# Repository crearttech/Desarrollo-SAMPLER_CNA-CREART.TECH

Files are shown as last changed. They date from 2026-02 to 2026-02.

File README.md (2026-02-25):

# DESARROLLO DE SAMPLER

**Looper / Sampler de audio en tiempo real construido sobre Daisy Seed.**

SAMPLER es un dispositivo de audio portátil que permite grabar, reproducir, sobreponer capas (overdub) y manipular loops en tiempo real con efectos y control visual mediante pantalla TFT.

Proyecto desarrollado por **Crearttech** y entregado al **CNA Centro Nacional de las Artes Delia Zapata Olivella** en Bogotá, Colombia.

---

## Características

- **Grabación y Reproducción** — Loop de hasta 10 segundos a 48kHz
- **Overdub** — Sobregrabar capas sobre el loop existente
- **Efectos en tiempo real** — Delay, Reverb, Pitch Shift, Filtros HP/LP
- **Reproducción reversa** — Inversión de la dirección de playback
- **Control de región** — Start/End point y movimiento del loop
- **Undo/Redo** — 3 niveles de historial
- **Pantalla TFT** — Visualización de waveform en tiempo real con interfaz de knobs circulares
- **Crossfade automático** — Transiciones suaves al cerrar el loop
- **Detección de jack** — Cambio automático entre entrada de línea y micrófono

## Hardware

| Componente | Descripción |
|---|---|
| Microcontrolador | Electro-Smith Daisy Seed (ARM Cortex-M7) |
| Pantalla | TFT ST7735 128×160 |
| Entrada de audio | ADC integrado del Daisy Seed |
| Salida de audio | DAC integrado del Daisy Seed |
| Controles | 4 Encoders rotativos con botón, 6 botones, LED RGB |

## Estructura del Código

```
SAMPLER_CNA/
├── SAMPLER_CNA.ino          # Programa principal (UI, controles, audio callback)
├── sampler_engine.h         # Motor de audio (grabación, playback, overdub, undo/redo)
├── sampler_effects.h        # Módulo de efectos (reverse, pitch shift, filtros)
├── sampler_dsp_utils.h      # Utilidades DSP optimizadas con CMSIS-DSP
├── sampler_state_machine.h  # Máquina de estados del looper
├── sampler_sync.h           # Sincronización de tempo y clock
└── sampler_hardware.h       # Mapeo de pines del Daisy Seed
```

## Instalación

1. Instalar [Arduino IDE](https://www.arduino.cc/en/software)
2. Instalar el board package **Electrosmith Daisy** desde el Board Manager
3. Instalar las bibliotecas:
   - `DaisyDuino`
   - `Adafruit GFX Library`
   - `Adafruit ST7735`
4. Abrir `SAMPLER_CNA/SAMPLER_CNA.ino`
5. Seleccionar board **Daisy Seed** y el puerto correspondiente
6. Compilar y subir

## Desarrolladores

**Crearttech**
- Andrés Melo
- Kelly Melo
- Rodrigo Aguilar

**En colaboración con DELIA**
- Javier Beltrán
- Santiago Gasca

**Crearttech** — Bogotá, Colombia, 2024

Proyecto entregado al **CNA Centro Nacional de las Artes Delia Zapata Olivella**, Bogotá, Colombia.

---

## Bibliografía y Referencias

### Hardware y Librerías Base
- **Electro-Smith**. (2020). *Daisy Seed Datasheet & Wiki*. [Daisy Seed Documentation](https://www.electro-smith.com/daisy/daisy).
- **DaisyDuino**. *Librería de soporte para el ecosistema Daisy en Arduino*. [GitHub Repository](https://github.com/electro-smith/DaisyDuino).
- **Adafruit Industries**. *Adafruit GFX Graphics Library*. [Documentation](https://learn.adafruit.com/adafruit-gfx-graphics-library).

### Procesamiento Digital de Señales (DSP)
- **Smith, S. W.** (1997). *The Scientist and Engineer's Guide to Digital Signal Processing*. California Technical Publishing.
- **Pirkle, W. C.** (2012). *Designing Audio Effect Plug-ins in C++*. Focal Press.
- **Zölzer, U.** (2011). *DAFX: Digital Audio Effects*. Wiley.

### Optimización y Algoritmos
- **ARM**. *CMSIS DSP Software Library Documentation*. [ARM Developer](https://arm-software.github.io/CMSIS_5/DSP/html/index.html).
- **D’Angelo, S., & Välimäki, V.** (2013). *Generalized Moog Ladder Filter*.

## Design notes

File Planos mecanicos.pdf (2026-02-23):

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

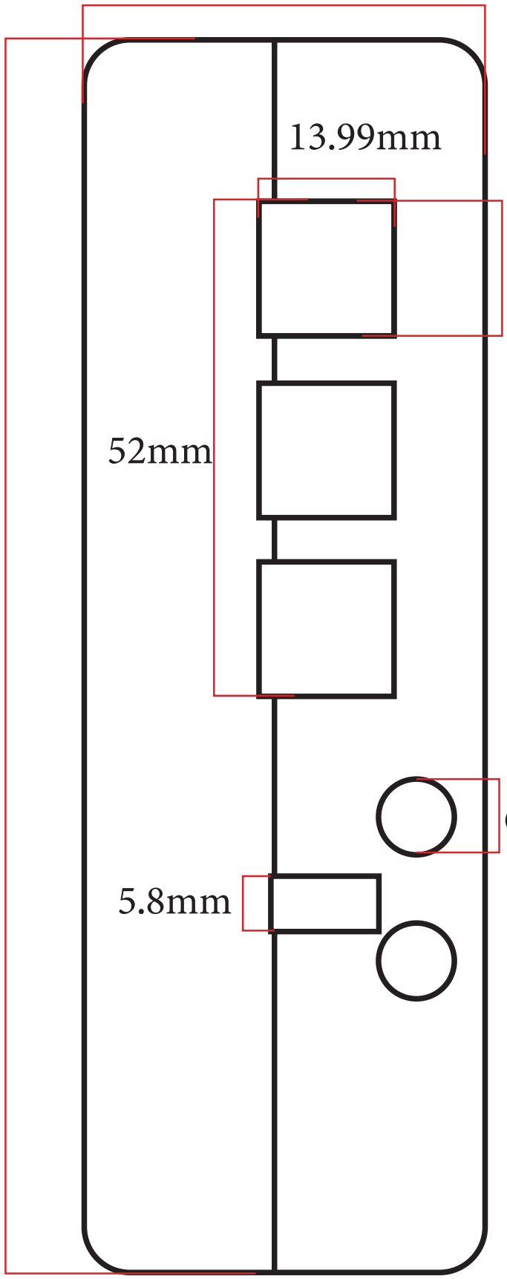
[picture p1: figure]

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

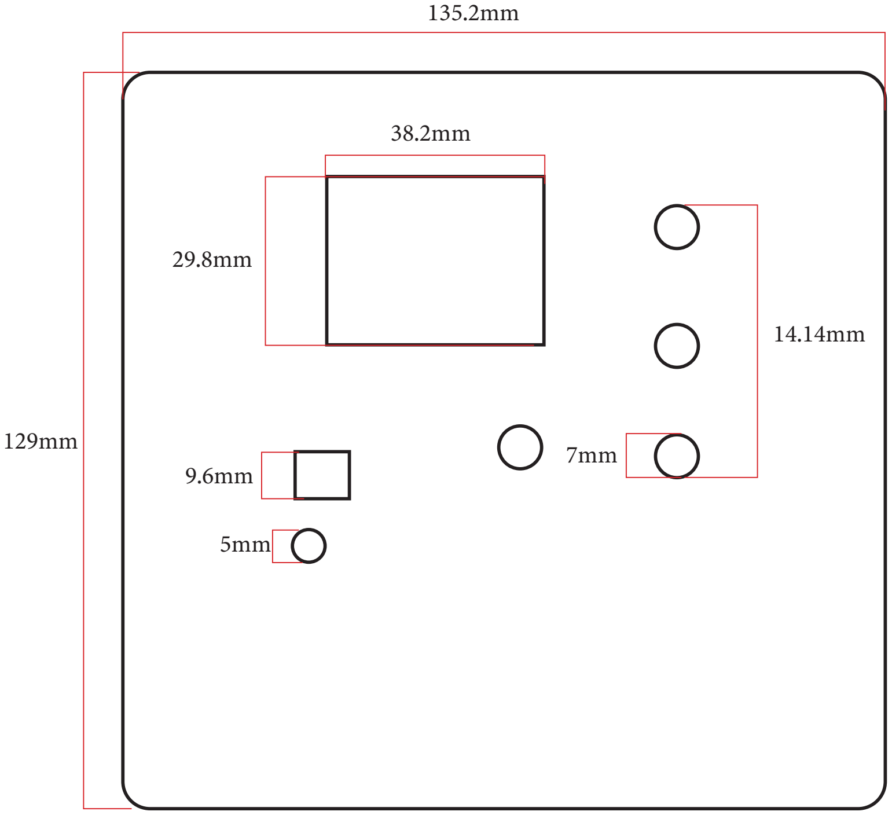
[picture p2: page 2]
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

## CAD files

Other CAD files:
PLANOS_MECANICOS_CASE.stl

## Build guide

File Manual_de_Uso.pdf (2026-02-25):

MANUAL DE USO

CODESARROLLO DE INSTRUMENTO ELECTRÓNICO MUSICAL

SAMPLER CNA + CREART.TECH

CENTRO NACIONAL DE LAS ARTES DELIA ZAPATA OLIVELLA

Bogotá D.C , Colombia

MANUAL DE USO

CODESARROLLO DE INSTRUMENTO ELECTRÓNICO MUSICAL

SAMPLER CNA + CREART.TECH

Presentado por :

CREART.TECH (SOUNDIFY STUDIO)

a

CENTRO NACIONAL DE LAS ARTES DELIA ZAPATA OLIVELLA

Bogotá D.C , Colombia

### 22 DE DICIEMBRE DE 2025

ÍNDICE :

1. Introducción
2. Conociendo el sampler
3. Encendido y flujo básico
4. Botones y Encoders
5. Guia de navegación
6. Exploración creativa
7. Integración
8. Resolución de problemas
9. Especificaciones técnicas
10. Glosario de términos

### 01. Introducción

Sampler CNA + Creart.Tech es una grabadora-sampler creativa basada en Daisy Seed, diseñada para capturar y manipular audio en tiempo real. Permite registrar sonidos, momentos e ideas, y procesarlos mediante coloración, modulación y edición sonora.

Es un instrumento versátil y preciso, listo para ser explorado, reinterpretado y llevado a nuevos territorios creativos.

Principios de diseño:

### 02. Conociendo el sampler

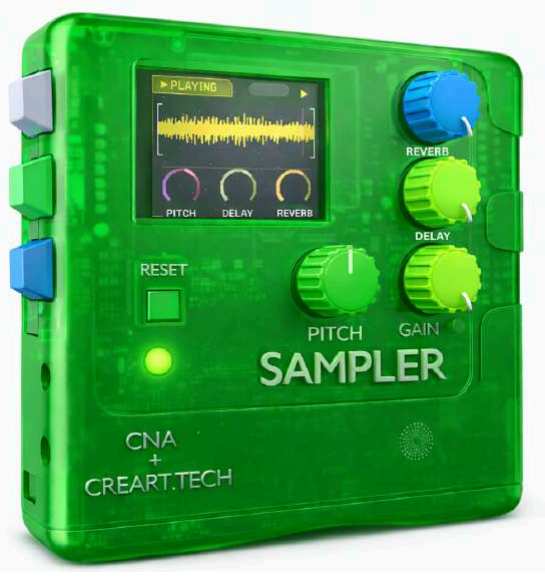
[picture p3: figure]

- Controles y conectores:
- Micrófono integrado (I2S)
- Entrada de línea 3.5 mm
- Encoders laterales y central
- Pantalla TFT
- LED de estado
- 3 teclas arcade

### 03. Encendido y flujo básico

Encendido:
Conecte un cable micro usb al microcontrolador Daisy seed. Espere a que la barra de carga se complete; cuando la interfaz esté activa, el dispositivo estará listo para su uso.

- Primer ejercicio rápido (“Quick Start”):

### 3 pasos para grabar y tocar un loop (ejercicio inmediato)

1. Mantener presionado el botón REC / OVERDUB, durante el tiempo que se desee que dure el sample.
2. Encoder GAIN, girando en sentido horario y antihorario.
3. Se presiona Encoder 1, se gira en sentido horario y antihorario para establecer punto de inicio; se presiona nuevamente Encoder 1 y se gira en sentido horario y antihorario para establecer punto de fin.
- Flujo funcional (Captura → Procesamiento → Reproducción → Efectos)

### 04. Botones y Encoders

Cada botón y encoder explicado con visual + acciones:
Grabación - Edición - Efectos

TECLA / BOTÓN 1:

REC / OVERDUB

Para una captura inicial, se debe mantener pulsado el botón durante todo el tiempo de grabación y soltar en el instante en el que se quiere detener la grabación. Una vez se deja de presionar el botón, el sampler, entra en modo loop, reproduciendo esta primera toma. Para hacer un OVERDUB, se debe presionar nuevamente el botón de manera sostenida durante toda la captura que se desea hacer y se debe soltar una vez haya terminado la captura.

TECLA / BOTÓN 2:

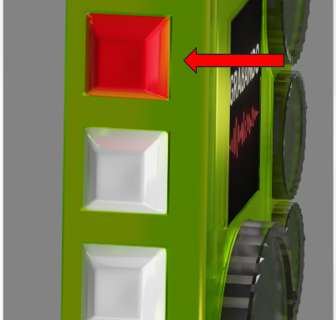
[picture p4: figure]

PLAY / PAUSE

Se presiona el botón una vez para detener la reproducción de audio y se debe presionar nuevamente una única vez para reanudar la reproducción del audio. Pulsando dos veces el mismo botón, sampler, entra en modo stop y se borrará todo el contenido grabado.

TECLA / BOTÓN 3:

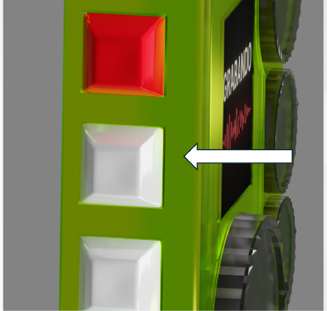
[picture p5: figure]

PLAYBACK - FORWARD / BACKWARD

Empieza a reproducir el audio por defecto hacia adelante. Se debe presionar el botón para backward que permite reproducir el loop en reversa, invirtiendo la dirección temporal del audio grabado.

TECLA / BOTÓN 4:

CUE / RESET

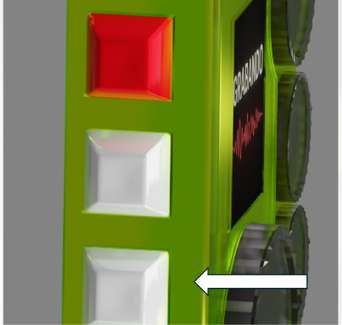
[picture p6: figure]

Se presiona una vez para volver al punto de inicio que se tenga marcado (cue) ya sea por defecto o por el punto de inicio de loop. Este botón permite reiniciar los efectos sin afectar el audio en curso. Pulsado una vez, se resetea el último cambio aplicado al audio y con dos pulsaciones resetea todos los cambios incluyendo el punto de inicio y punto de final del loop.

Encoder 1 (Reverb)

Controla los parámetros del efecto de Reverb. Tiene tres parámetros que se pueden alternar con una pulsación para cambiar entre ellos y son: MIX, SIZE y DECAY. Al cambiar de modo, el contador del encoder se actualiza al valor guardado que se puede establecer con el giro del encoder, modificando el valor del parámetro actualmente seleccionado (de 0% a 100%), girando el encoder en sentido horario y antihorario para mover el cursor de izquierda a derecha o de derecha a izquierda respectivamente.

Encoder 2 (Delay)

Controla los parámetros del efecto de Delay. Tiene tres parámetros que se pueden alternar con una pulsación para cambiar entre ellos y son: MIX, TIME y FEEDBACK. Al cambiar de modo, el contador del encoder se actualiza al valor guardado que se puede establecer con el giro del encoder, modificando el valor del parámetro actualmente seleccionado (de 0% a 100%), girando el encoder en sentido horario y antihorario para mover el cursor de izquierda a derecha o de derecha a izquierda respectivamente.

Encoder 3 (GAIN, START/END POINT & MOVE)

Permite ajustar cuatro parámetros principales: Gain, Start Point, End Point y Move. Cada vez que se presiona el encoder, se avanza al siguiente modo de edición en el orden indicado.

### 1. Modo Gain (por defecto)

- El encoder ajusta el volumen de la muestra.
- Girar en sentido horario aumenta el nivel; girar en sentido antihorario disminuye el nivel.
- Aunque el encoder tiene rotación continua, el volumen está limitado entre 0 % y 100 %.
- Para confirmar el nivel de volumen y continuar al siguiente parámetro, presionar el encoder.

### 2. Modo Start Point

- Tras la pulsación, el encoder pasa a controlar el punto de inicio del loop.
- Girar en sentido horario mueve el cursor de inicio hacia la derecha; en sentido antihorario, hacia la izquierda.
- Una vez establecido el punto de inicio, presionar el encoder para fijarlo y pasar al siguiente parámetro.

### 3. Modo End Point

- El encoder permite definir el punto de final del loop.
- Girar en sentido horario mueve el cursor hacia la derecha; en sentido antihorario, hacia la izquierda.
- Al confirmar el punto de final con una pulsación, se avanza al último modo.

### 4. Modo Move

- En este modo, el encoder desplaza el loop completo, moviendo simultáneamente el Start Point y el End Point.
- Girar en sentido horario desplaza el loop hacia la derecha; girar en sentido antihorario lo desplaza hacia la izquierda.
- Una nueva pulsación regresa el encoder nuevamente al modo Gain.

Encoder 4 Central (Pitch & Filtros)

PITCH
Controla el pitch girando el encoder en sentido horario y antihorario para mover el cursor de inicio de izquierda a derecha o de derecha a izquierda respectivamente, lo que cambia el valor de pitch, que se traduce directamente en la transposición de semitonos. El rango está limitado de -128 semitonos a +128 semitonos. Con una pulsación del botón de CUE/RESET, se resetea el pitch a 0 semitonos, lo que permite regresar a la tonalidad original. Este rango en semitonos abarca tanto 10 octavas + 8 semitonos de forma ascendente así como 10 octavas + 8 semitonos de forma descendente.

FILTROS
Este modo permite quitar contenido frecuencial de la muestra, girando el encoder en sentido horario y antihorario para mover el cursor de izquierda a derecha o de derecha a izquierda respectivamente, permitiendo elegir la frecuencia de corte comprendidas entre 20Hz y 20kHz permitiendo filtrar el contenido a partir de dicha frecuencia.

High Pass

Pulsando una vez el encoder, luego de haber establecido un valor de pitch, se podrá cambiar la frecuencia de corte del filtro high pass, permitiendo pasar todo el contenido frecuencial a partir de la frecuencia de corte en adelante (las frecuencias altas).

Con una pulsación del botón de CUE/RESET, se resetea el filtro aplicado.

Low Pass
Luego con otra pulsación, luego de haber establecido una frecuencia de corte para el filtro high pass, se podrá cambiar la frecuencia de corte del filtro low pass, permitiendo pasar todo el contenido frecuencial a partir de la frecuencia de corte hacia atrás (las frecuencias bajas).

Con una pulsación del botón de CUE/RESET, se resetea el filtro aplicado.

### 0.5 Guia de navegación

Control físico | Acción del usuario | Función asignada | Criterio de diseño / Uso musical

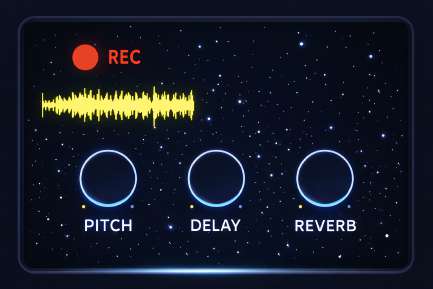
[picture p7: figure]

| Botón 1 REC | Mantener pulsado | Inicia la grabación del loop | Permite control preciso de la duración del loop
| | Soltar | Finaliza grabación e inicia reproducción | Flujo natural grabar → reproducir
| | Pulsación posterior | Activa modo Overdub | Superposición de capas sonoras sin interrumpir ejecución

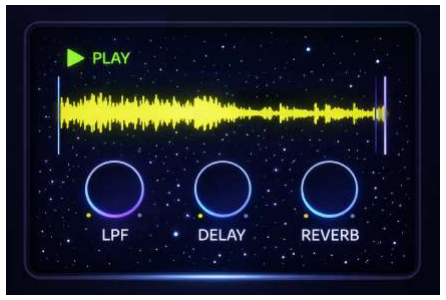
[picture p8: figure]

| Botón 2 | Pulsación simple | Play / Pause del loop | Detener y reanudar sin reiniciar

Transporte

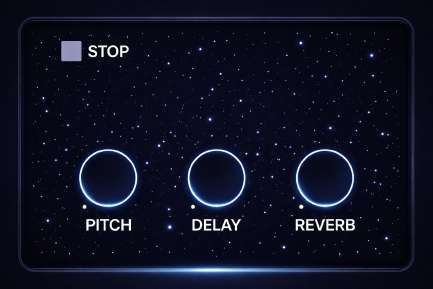
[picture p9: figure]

| Doble pulsación | Stop y borrado de audio | Reinicio rápido del buffer de memoria

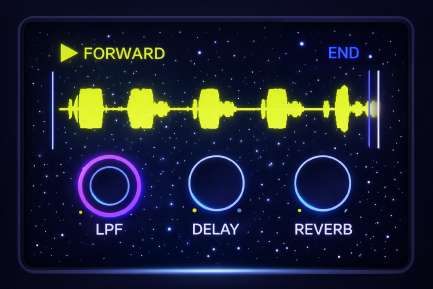
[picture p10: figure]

Botón 3 Dirección | Pulsación | Forward (por defecto) | Reproducción temporal estándar
| Pulsación alterna | Backward | Reproducción en reversa para exploración expresiva

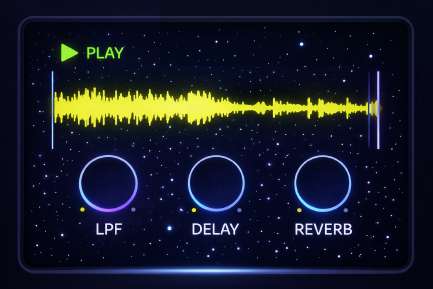
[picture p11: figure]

Botón 4 Reset | Pulsación simple | Reset de efectos | Limpieza sonora sin afectar el audio
| Doble pulsación | Reset de Start Point y End Point | Reconfiguración estructural del loop

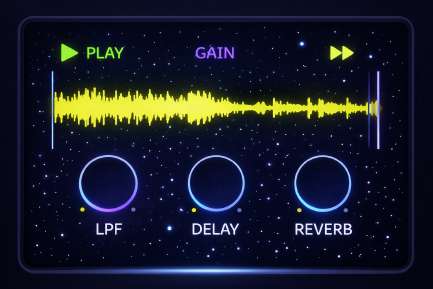
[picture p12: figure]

Encoder 1 Loop | Pulsación | Cambio de modo | Navegación entre parámetros del loop
| Giro | Gain | Control de amplitud del audio

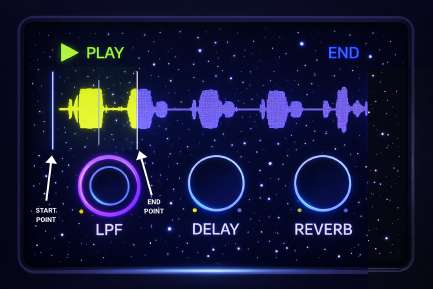
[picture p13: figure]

| Giro | Start Point | Ajuste del punto de inicio del loop
| Giro | End Point | Ajuste del punto final del loop
| Giro | Move | Desplazamiento temporal del loop

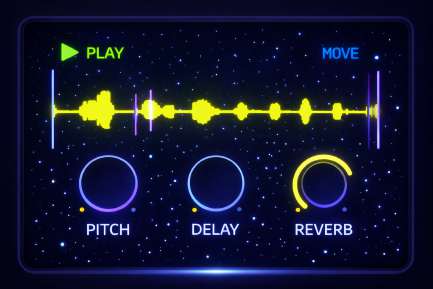
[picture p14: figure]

Encoder 2 Reverb | Pulsación | Cambio de modo (MIX / SIZE / DECAY) | Navegación simple sin menús
| Giro | Ajuste de parámetro (0–100) | Control progresivo y continuo

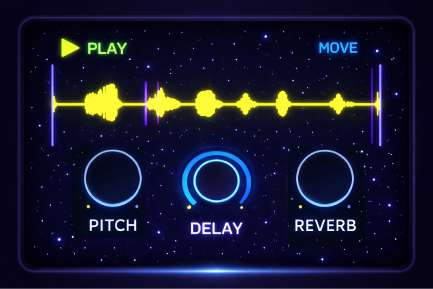
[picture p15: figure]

Encoder 3 Delay | Pulsación | Cambio de modo (TIME / FEEDBACK / MIX) | Control estructurado del efecto
| Giro | Ajuste de parámetro (0–100) | Manipulación expresiva del tiempo

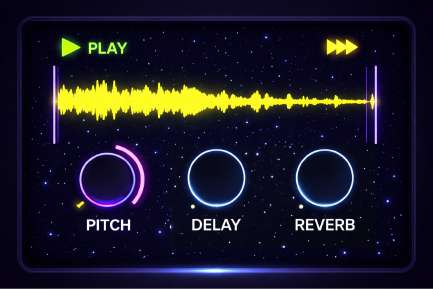
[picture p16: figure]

Encoder 4 Pitch | Giro | ±7 semitonos | Modifica afinación y velocidad del loop
| | Agudo | Reproducción más rápida
| | Grave | Reproducción más lenta

Encoder 4 Filtros | Giro | High-Pass | Eliminación de frecuencias bajas
| Giro | Low-Pass | Eliminación de frecuencias altas

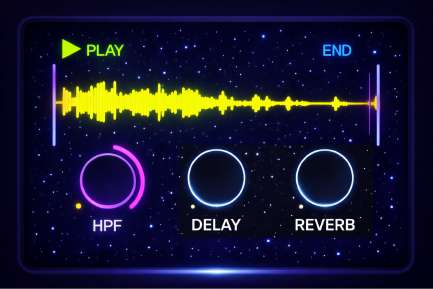
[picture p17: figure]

### 06. Exploración creativa

Ejemplos de uso artístico:

“Grabe un sonido cotidiano y conviértalo en ritmo.”

Grabe un ritmo sencillo, puede golpear una mesa con las manos, haga chopping para conservar sólo el instante en el que se percibe el fragmento del golpe cortando así todo lo demás que se haya podido colar en la grabación, aplique filtros high pass y low pass, cortando el contenido frecuencial innecesario sin cortar demasiado evitando filtrar el ataque en alta frecuencia y el cuerpo en baja presencia, puede bajar la tonalidad un par de semitonos para un sonido más grave, aplicar reverb, con un size mediano, un decay corto y un mix entre el 20% y 40% (puede explorar distintos valores según el gusto).

RESULTADO: obtendrá un sonido más espaciado y por tanto un bombo al son de tu ritmo.

“Transforme un susurro en un pad atmosférico”

Capture un susurro o respiración suave, baje el pitch para alargar la sensación y dar más cuerpo. use low-pass para suavizar y high-pass para limpiar graves innecesarios, puede jugar con el punto de corte para moldear el timbre. Aplique un delay con feedback bajo y tiempo largo para simular movimiento y repetición, agregue una reverb extensa (decay alto, mix 60–80%) para generar la atmósfera envolvente.

RESULTADO: un pad etéreo que se construye con capas de pitch + delay + reverb, sin necesidad de time-stretch ni moduladores.

“Construya percusión con objetos metálicos”
Grabe el sonido de llaves, monedas o utensilios metálicos, corte los fragmentos más brillantes y cortos para usarlos como hits, baje algunos samples para simular percusión grave (tipo toms) y suba otros para hi-hats. Use low-pass para dar cuerpo a los graves y high-pass para resaltar los agudos metálico, aplique delay rítmico sincronizado al tempo para crear patrones repetitivos y agregue reverb corta y controlada para dar cohesión sin perder ataque.

RESULTADO: un kit alternativo de percusión metálica, con carácter industrial y experimental.

### 07. Integración

- Conexión a otros equipos: pedales, sintetizadores, interfaces y Daws.

TIPO DE CONEXIONES EXTERNAS PERMITIDAS PARA sampler

Solo conectores TRS de 3.5mm o de 6.35mm con su respectivo adaptador a 3.5mm, o cualquier otro tipo de adaptador que permita físicamente hacer la conexión y que se respete el nivel y la impedancia de un conector TRS.
❖ Una señal de línea por conector TRS suele tener un nivel típico entre –10 dBV (≈ 0,316V RMS) e idealmente +4 dBu (≈1,23V RMS) con una impedancia de salida típica entre 100–600 Ω.

CONEXIÓN DE ENTRADAS EXTERNAS

Puedes conectar a sampler diversas fuentes de audio externas cuya salida sea de carácter análogo, que sea nivel de línea y que se pueda conectar por cable TRS de 3.5mm, estas pueden ser:

- Reproductores de música domésticos
- CD players, DVD players
- Reproductores de cassette
- Radios y sintonizadores FM/AM
- Fuentes modernas de consumo
- Smartphones, tablets y laptops (a través de su salida de auriculares con un adaptador a nivel de línea)
- Interfaces de audio USB con salidas analógicas Jack 3.5mm
- Instrumentos musicales con preamplificador
- Teclados electrónicos y sintetizadores (la mayoría entregan salida de línea)
- Drum machines y samplers
- Guitarras/bajos eléctricos con pedal o preamp externo (sin eso, la señal es de nivel instrumento, no línea)

- Equipos profesionales de estudio
- Consolas de mezcla (salidas Main Out o Aux Out)
- Preamplificadores de micrófono con salida desbalanceada a nivel de línea
- Procesadores de efectos externos (rack FX, compresores, reverbs)
- Fuentes audiovisuales
- Televisores y decodificadores con salida TRS de 3.5mm o RCA con su respectiva conversión a TRS de 3.5mm.
- Cámaras de video con salida de línea.

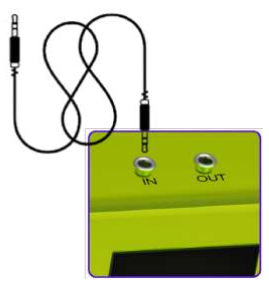
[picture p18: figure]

Cómo samplear desde otros instrumentos.

Conecte la salida del instrumento a la entrada TRS de 3.5mm del sampler

- Asegúrese de que el instrumento entregue nivel de línea (teclados, sintetizadores, drum machines, pedales o preamps).
- Si la señal es de nivel instrumento (ej. guitarra/bajo directo), utilice un pedal o preamplificador externo para elevarla a nivel de línea.

Ajuste el volumen de salida del instrumento para evitar saturación.

- Empiece con un nivel medio y haga pruebas de grabación.
- Si el sonido distorsiona, baje el volumen en el instrumento o en el pedal/preamp.

Grabe el fragmento deseado directamente en el sampler.

- Puede capturar frases melódicas, acordes, golpes rítmicos o texturas sostenidas.
- Mantenga la señal lo más limpia posible para facilitar la edición posterior.

Procese el sample dentro del sampler usando las herramientas disponibles:

- Chopping para aislar golpes o notas.
- Pitch shifting para variar la tonalidad.
- Filtros low/high pass para moldear el timbre.
- Reverb y delay para dar espacio y profundidad.

Integre el sample en el set creativo:

- Úselo como base rítmica, como textura ambiental o como elemento melódico.
- Experimente con capas y variaciones para enriquecer su composición.

### 08. Resolución de problemas

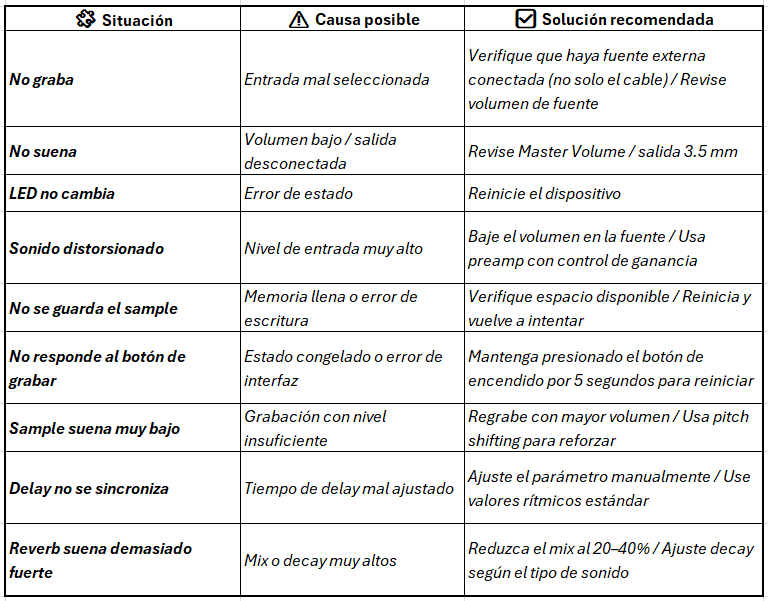
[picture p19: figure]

### 09. Especificaciones técnicas

Audio
- Conversión digital: 96 kHz / 24 bits estéreo (basado en Daisy Seed)
- Micrófono integrado: electret, conmutable con entrada de línea externa
- Entrada de línea: TRS, conmutable con micrófono integrado
- Ganancia máxima de entrada: +60 dB
- Altavoz integrado: mono, acoplado para monitoreo directo
- Salida de línea: TRS, conmutable con el altavoz integrado
- Tiempo máximo de grabación:10 minutos
- Limitaciones:
- DAC interno de 12 bits (para salidas analógicas directas)

- Requiere | adaptación | de | niveles | para | fuentes | externas
(instrumento/micrófono profesional)
- Sin preamplificación dedicada para micrófonos externos

Conectividad y sistema
- Basado en Daisy Seed ARM Cortex-M7 @ 480 MHz
- Memoria SDRAM: 64 MB (≈10 min de audio buffer)
- Flash interna: 8 MB
- USB: micro USB OTG (host/dispositivo)

10.Glosario de términos:

- REC: De su abreviación en inglés para “record”, hace referencia a la palabra “grabar”, que para este caso se refiere a la grabación (captura) de una muestra de audio.
- OVERDUB: Del inglés hace referencia a la palabra “sobre grabación”, hace referencia a la técnica de superponer una nueva grabación de audio sobre una grabación existente para añadir capas, enriquecer una pista o corregir errores.
- PLAYBACK: Del inglés hace referencia a la palabra “reproducción”, que para este caso se refiere a la reproducción de una o varias muestras de audio.
- FORWARD: Del inglés hace referencia a la palabra “adelante”, que para este caso se refiere a la reproducción de una o varias muestras de audio hacia adelante.
- BACKWARD: Del inglés hace referencia a la palabra “hacia atrás”, que para este caso se refiere a la reproducción de una o varias muestras de audio hacia atrás.
- PLAY: Del inglés también hace referencia a “reproducir audio”, con la distinción de que reproduce una o varias muestras de audio para quién llama o ejecuta dicha acción de reproducción de manera arbitraria.
- PAUSE: Del inglés hace referencia a la palabra “pausa”, que para este caso se refiere a la detención de la reproducción para quién llama o ejecuta dicha acción de reproducción de manera arbitraria.
- CUE: En audio, "cue" puede referirse a varias funciones, como un punto de inicio en una pista de música para DJs, una unidad de sonido sincronizada en bandas sonoras de películas, o un archivo de texto que describe la estructura de un disco compacto. También se refiere a la función de preescucha en consolas de mezcla, que permite oír un canal individualmente sin que salga por los altavoces principales. En este caso hace referencia al punto de inicio del loop determinado por el usuario.

- RESET: Del inglés significa “reiniciar” y en este caso, permite reiniciar los efectos sin afectar el audio en curso.
- LOOP: Del inglés significa “bucle” y en este caso es una sección de sonido que se repite indefinidamente de inicio a fin, creando una sensación de continuidad o un patrón musical, que es por defecto la muestra que se toma y se reproduce en bucle y puede ser definida por el usuario.
- FEEDBACK: Del inglés significa “realimentación”, es un acople o silbido molesto que se produce cuando el sonido de un altavoz es captado por un micrófono y reamplificado en un bucle continuo. Este ciclo se genera por la retroalimentación de la señal, donde el sonido amplificado vuelve a entrar en el micrófono, creándose un círculo interminable que se vuelve cada vez más fuerte hasta generar el ruido característico.
- ENCODER: Del inglés significa “codificador/a”, y es un dispositivo electromecánico o electrónico que convierte el movimiento (rotativo o lineal) en señales eléctricas que un sistema de control puede interpretar. Estas señales se utilizan para medir y controlar la posición, la velocidad y la dirección de un objeto o eje.
- GAIN: Del inglés significa “ganancia ”, y es la cantidad de amplificación que se le da a una señal de audio, ajustando el nivel de la señal de entrada para que sea lo suficientemente fuerte antes de ser procesada.
- REVERB: Del inglés significa “reverberación”, es un efecto de audio que simula el sonido de un espacio, como una habitación, una sala de conciertos o una catedral. Crea la sensación de profundidad y ambiente al imitar las reflexiones del sonido en las superficies de un entorno.
- SIZE: Del inglés significa “tamaño”, en un efecto de reverberación se refiere al tamaño virtual del espacio en el que se simula la acústica. Un valor de tamaño pequeño imita un espacio pequeño como un armario o un dormitorio, mientras que un valor grande simula un espacio grande como un auditorio o una catedral.
- DECAY: Del inglés significa “decadencia”, y se refiere al tiempo que tarda la cola de la reverberación en desvanecerse por completo después de que el sonido original deja de sonar. Un decay largo crea una cola de reverb que dura más tiempo, como en un espacio grande, mientras que un decay corto resulta en una reverberación que se apaga más rápido.
- MIX: Del inglés significa “mezcla”, se refiere a la combinación de la señal original de audio (dry) con la señal procesada por un efecto de reverberación (wet), controlando el balance entre ambas para dar al sonido una sensación de espacio y profundidad.
- DELAY: Del inglés significa “retardo”, y se refiere a un efecto de sonido que consiste en repetir una señal sonora con un retardo de tiempo, creando un efecto similar al eco. Este efecto se logra al duplicar la señal original y reproducir la copia después de un período específico.
- TIME: Del inglés significa “tiempo” y es el parámetro que determina el tiempo de retardo entre la señal original y su repetición o "eco". Este tiempo se puede ajustar en milisegundos o segundos, o sincronizarse con el tempo de la canción para que las repeticiones sigan un patrón rítmico (como corcheas o negras).
- FEEDBACK: Del inglés significa “realimentación”, que controla cuántas repeticiones del sonido original se escucharán. Determina la cantidad de señal que se reenvía al delay para crear repeticiones sucesivas y se mide como un porcentaje, donde un valor alto resulta en más repeticiones que se desvanecen lentamente y un valor bajo crea solo una o dos repeticiones.
- MIX: Del inglés significa “mezcla”, se refiere a la combinación de la señal original de audio (dry) con la señal procesada por un efecto de reverberación (wet), controlando el balance entre ambas para dar al sonido una sensación de espacio y profundidad.
- PITCH: En audio, el pitch es la altura o la afinación de un sonido, es decir, qué tan agudo o grave es. Se relaciona con la frecuencia fundamental del sonido y se puede modificar para subir o bajar el tono de una voz o un instrumento, a menudo alterando también su velocidad, aunque existen técnicas para cambiar el pitch sin afectar la velocidad.
- SEMITONO: Un semitono es el intervalo musical más pequeño entre dos notas consecutivas en la música occidental. Equivale a la mitad de un tono y se visualiza como la distancia entre dos teclas adyacentes en un piano, sin ninguna tecla en medio.
- OCTAVA: En audio, una octava es el intervalo entre dos sonidos donde la frecuencia de uno es exactamente el doble de la del otro. Este intervalo se considera uno de los más consonantes y es fundamental en música, ya que dos notas separadas por una octava suenan muy similares y comparten el mismo nombre, pero en una altura diferente. En la práctica, como en un piano, el sonido de un "Do" y el siguiente "Do" representan una octava, una más aguda y otra más grave.
- CONECTOR TRS: Un conector TRS (Tip-Ring-Sleeve, o Punta-Anillo-Funda en español) es un tipo de enchufe de audio que tiene tres partes conductoras: la punta, el anillo y la funda. Su función principal es transportar señales de audio de alta calidad, ya sea para señales mono balanceadas o estéreo únicamente para este caso. Son muy utilizados en audio profesional para conectar instrumentos, micrófonos, mezcladores y auriculares estéreo.
- FILTRO HIGH PASS: Del inglés, significa “pasa altos”, y es un tipo de filtro de audio que permite el paso de las frecuencias por encima de una frecuencia de corte seleccionada y atenúa o elimina las frecuencias más bajas. Se utiliza para limpiar el sonido al eliminar ruidos de baja frecuencia no deseados, como el rumbling del tráfico, el aire acondicionado o las consonantes explosivas en una voz
- FILTRO LOW PASS: Del inglés, significa “pasa bajos”, y es un tipo de filtro que permite el paso de las frecuencias bajas y atenúa las frecuencias altas por encima de un punto de corte definido. Su función principal es eliminar o reducir los sonidos agudos y "limpiar" la señal de audio para que solo las frecuencias bajas (graves) pasen libremente.
- CHOPPING: Del inglés, significa “cortar”, se refiere a la técnica de dividir una muestra de audio como una voz, un sample o un instrumento en pequeños fragmentos y luego reorganizarlos para crear una nueva melodía, ritmo o textura. Es una técnica común en la música electrónica, hip-hop y pop para crear ganchos pegadizos.
- SAMPLE: Del inglés, significa “muestra” que en audio es un fragmento de sonido extraído de una grabación existente para ser reutilizado en una nueva composición. Este fragmento puede ser una melodía, un ritmo de batería, una línea vocal o cualquier otro sonido grabado y puede ser manipulado para crear una pieza musical completamente nueva.

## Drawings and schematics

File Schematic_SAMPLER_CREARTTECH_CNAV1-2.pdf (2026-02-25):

LP103665

IN+

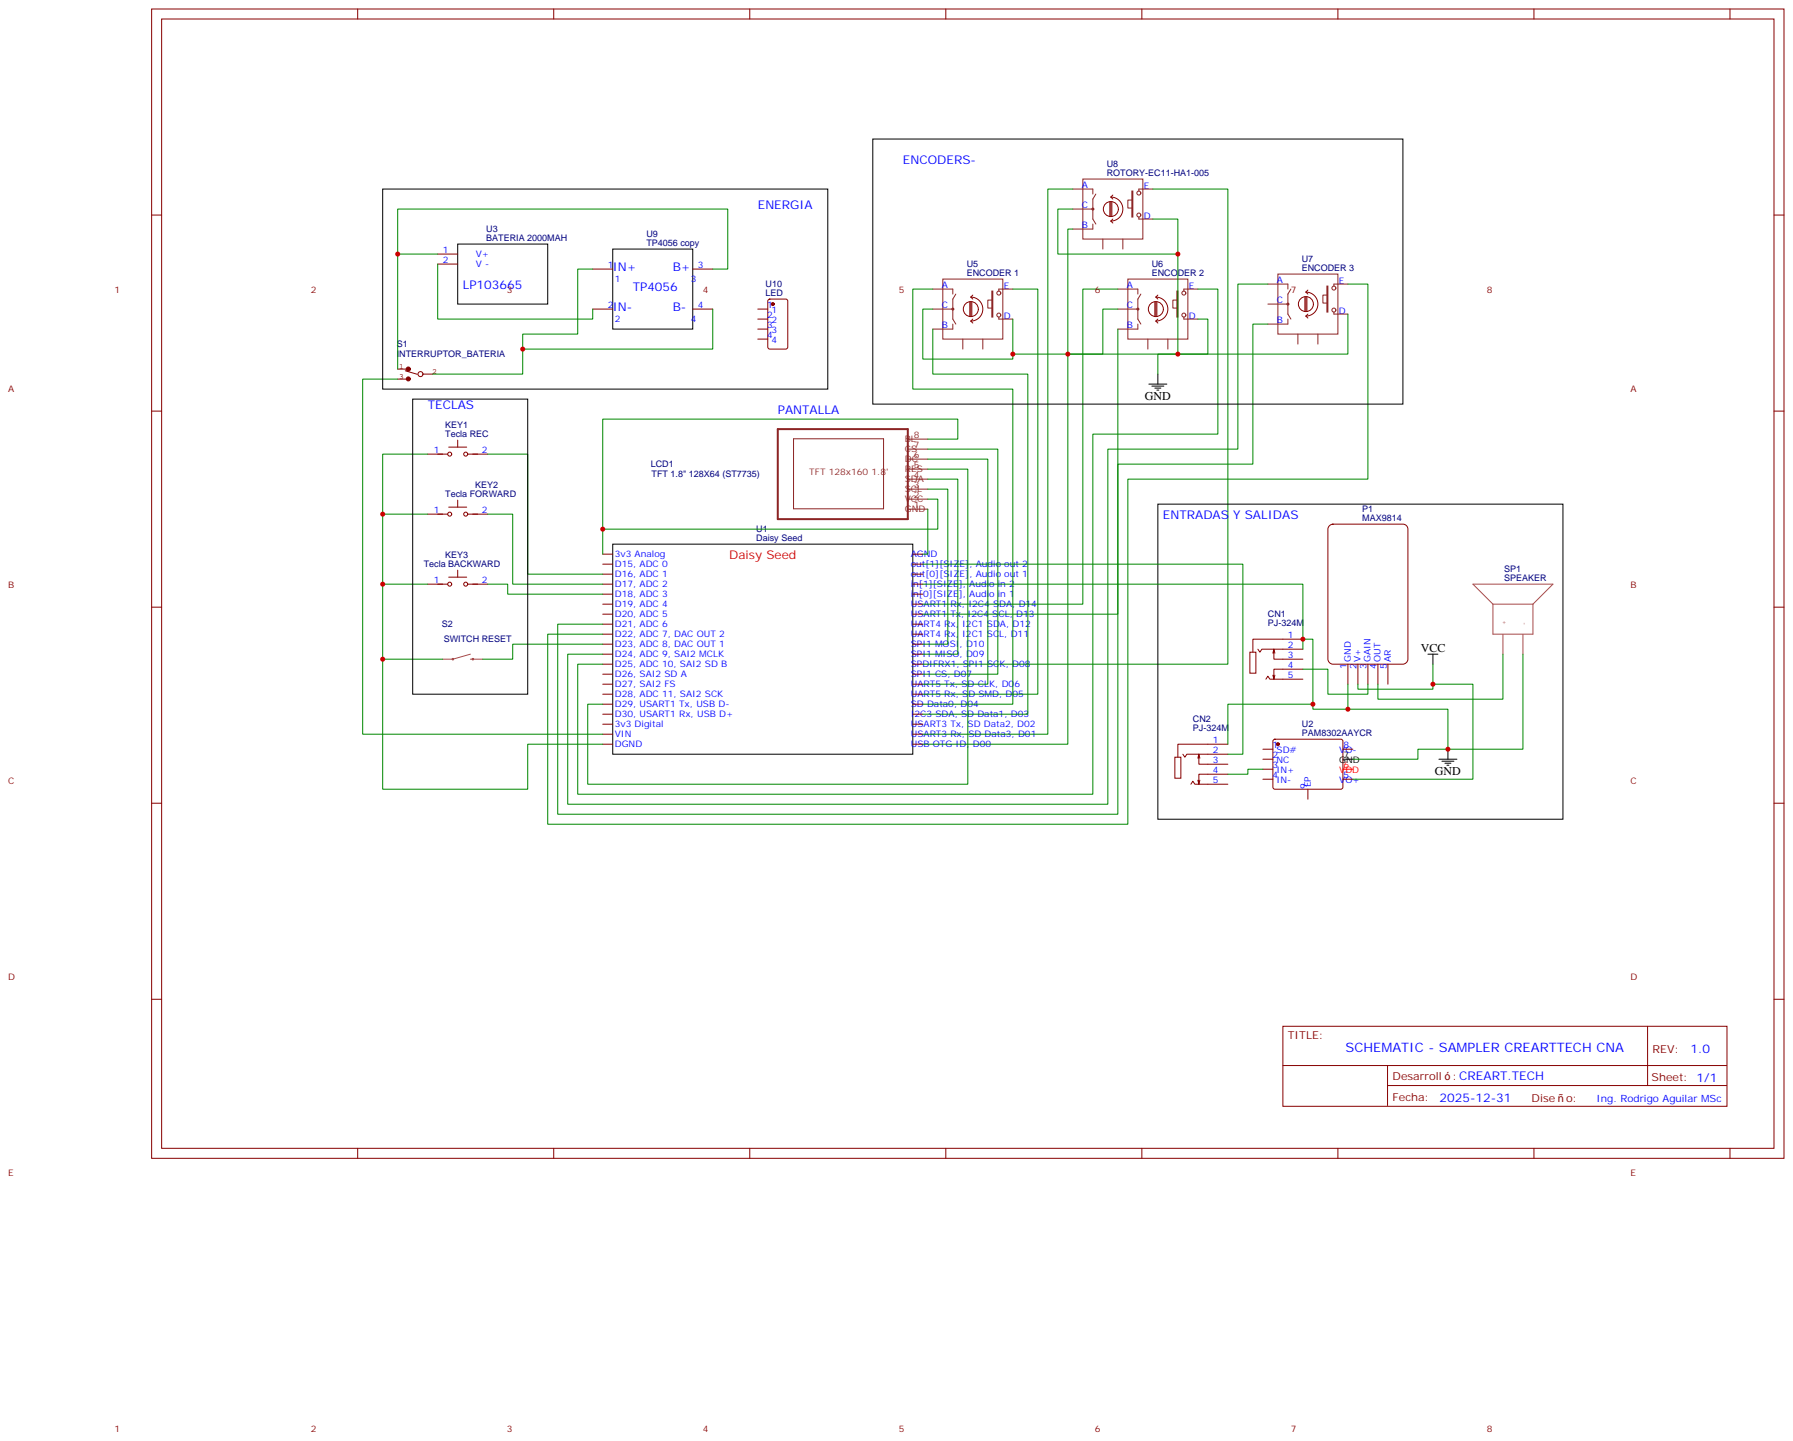
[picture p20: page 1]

out[1][SIZE], Audio out 2
out[0][SIZE], Audio out 1
in[1][SIZE], Audio in 2
in[0][SIZE], Audio in 1
USART1 Rx, I2C4 SDA, D14
USART1 Tx, I2C4 SCL, D13
UART4 Rx, I2C1 SDA, D12
UART4 Rx, I2C1 SCL, D11
SPI1 MOSI, D10
SPI1 MISO, D09
SPDIFRX1, SPI1 SCK, D08
SPI1 CS, D07
UART5 Tx, SD CLK, D06
UART5 Rx, SD SMD, D05
SD Data0, D04
I2C3 SDA, SD Data1, D03
USART3 Tx, SD Data2, D02
USART3 Rx, SD Data3, D01
USB OTG ID, D00

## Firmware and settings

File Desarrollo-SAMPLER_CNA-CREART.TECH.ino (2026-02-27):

/**
 * ===================================================================== 
 * ===================================================================== 
 * Simple Looper para Daisy Seed con Salida de Audio Analógica (Interna)
 * Corregido: waveform estilo Ableton (calculo al finalizar la grabación) 
 * ===================================================================== 
 */
#include <DaisyDuino.h>
#include <new>
#include <Adafruit_GFX.h>
#include <Adafruit_ST7735.h>
#include <SPI.h>
#include <math.h>
#include "sampler_engine.h"
#include "sampler_hardware.h"


using namespace daisy;

#define AUDIO_SAMPLE_RATE 48000
#define AUDIO_BLOCK_SAMPLES 48

// --- DEFINICIONES DE PANTALLA ---
#define SCREEN_WIDTH 160
#define SCREEN_HEIGHT 128
GFXcanvas16* canvas = NULL;

//====================================================================
const uint8_t Font_04_B_30__12pt7bBitmaps[] PROGMEM = {};
const GFXglyph Font_04_B_30__12pt7bGlyphs[] PROGMEM = {};
const GFXfont Font_04_B_30__12pt7b PROGMEM = {
  (uint8_t*)Font_04_B_30__12pt7bBitmaps,
  (GFXglyph*)Font_04_B_30__12pt7bGlyphs,
  0x20, 0x7E, 24
};

//====================================================================
// --- CONFIGURACIÓN DE PINES ---
//====================================================================
#define TFT_CS D7
#define TFT_DC D6
#define TFT_RST D29
#define TFT_MOSI D10
#define TFT_SCK D8
Adafruit_ST7735 tft = Adafruit_ST7735(TFT_CS, TFT_DC, TFT_RST);

#define REC_BUTTON_PIN D16
#define PLAY_BUTTON_PIN D17
#define STOP_BUTTON_PIN D18
#define BACK_BUTTON_PIN D22
#define FN_BUTTON_PIN D29
#define RESET_BUTTON_PIN D23  // Botón de reseteo
#define JACK_DETECT_PIN D2   // Pin para detectar si el jack de línea está conectado

const unsigned long BUTTON_DEBOUNCE_DELAY = 50;

#define ENC1_CLK_PIN D0
#define ENC1_DT_PIN D1
#define ENC1_SW_PIN D9

#define ENC2_CLK_PIN D3
#define ENC2_DT_PIN D4
#define ENC2_SW_PIN D5

#define ENC3_CLK_PIN D13
#define ENC3_DT_PIN D14
#define ENC3_SW_PIN D25

#define ENC4_CLK_PIN D20
#define ENC4_DT_PIN D21
#define ENC4_SW_PIN D24

const int PITCH_SENSITIVITY = 4; // 4 pulsos por semitono para un control más fino

static const int record_led_pin = D15;


#define LED_G_PIN D26 // Verde
#define LED_B_PIN D27 // Azul
#define LED_R_PIN D28 // Rojo

//====================================================================
// --- BÚFERES DE AUDIO ---
//====================================================================
static const uint32_t kBufferLengthSec = 10;
static const uint32_t kSampleRate = 48000;
static const size_t kBufferLengthSamples = kBufferLengthSec * kSampleRate;

// Buffers alineados a 32 bytes para optimización de caché (Cortex-M7)
static float DSY_SDRAM_BSS buffer[kBufferLengthSamples] __attribute__((aligned(32)));
static float DSY_SDRAM_BSS waveform_source_buffer[kBufferLengthSamples] __attribute__((aligned(32)));

// Ring buffer de undo/redo - 3 niveles
static float DSY_SDRAM_BSS undo_buffer_0[kBufferLengthSamples] __attribute__((aligned(32)));
static float DSY_SDRAM_BSS undo_buffer_1[kBufferLengthSamples] __attribute__((aligned(32)));
static float DSY_SDRAM_BSS undo_buffer_2[kBufferLengthSamples] __attribute__((aligned(32)));

// Array de punteros para pasar al looper
static float* undo_buffers[3] = {undo_buffer_0, undo_buffer_1, undo_buffer_2};

//====================================================================
// --- OBJETOS DE AUDIO Y ESTADOS GLOBALES ---
//====================================================================

static crearttech::OverdubLooper looper;
static daisysp::PitchShifter pitch_shifter;
static daisysp::Svf* g_highpass_filter;
static daisysp::Svf* g_lowpass_filter;
static uint8_t DSY_SDRAM_BSS reverb_memory[sizeof(daisysp::ReverbSc)];
static daisysp::ReverbSc* reverb_effect;
static daisysp::DelayLine<float, 4800> delay_effect;

enum LooperState { STOPPED, RECORDING, PLAYING, OVERDUB, PAUSED };
LooperState looper_state = STOPPED;

enum GlobalMode { MODE_INICIO, MODE_EDICION, MODE_FX };
GlobalMode current_mode = MODE_EDICION;

enum Knob2Mode { REVERB, SIZE, DECAY };
Knob2Mode knob2_mode = REVERB;

enum Knob3Mode { TIME, DELAY, MIX };
Knob3Mode knob3_mode = TIME;

enum Enc1Mode { PITCH, HIGHPASS, LOWPASS };
Enc1Mode enc1_mode = PITCH;
static float g_current_pitch_ratio = 1.0f;
static float g_playback_speed = 1.0f;

#define REV_BUTTON_PIN D19

bool last_rec_button_state = HIGH, last_play_button_state = HIGH, last_stop_button_state = HIGH, last_back_button_state = HIGH, last_rev_button_state = HIGH;
bool last_enc1_sw_state = HIGH, last_enc2_sw_state = HIGH, last_enc3_sw_state = HIGH, last_enc4_sw_state = HIGH;
bool last_fn_button_state = HIGH;

const unsigned long DOUBLE_PRESS_TIME_MS = 500;
unsigned long lastPlayPressTime = 0;
int playPressCount = 0;
unsigned long last_rev_button_press_time = 0;
unsigned long last_stop_press_time = 0;
int stop_press_count = 0;
unsigned long last_reset_press_time = 0;
int reset_press_count = 0;
bool last_reset_button_state = HIGH;
volatile int enc1_counter = 0, enc2_counter = 0, enc3_counter = 0;
static int last_e1 = 0, last_e2 = 0, last_e3 = 0;
volatile int enc4_counter = 0;
volatile unsigned long last_isr_time_4 = 0;
static int last_e4 = 0;

enum Enc4Mode {
    ENC4_MODE_START_POINT,
    ENC4_MODE_END_POINT,
    ENC4_MODE_MOVE,
    ENC4_MODE_GAIN 
};
Enc4Mode enc4_mode = ENC4_MODE_GAIN;

static float g_gain = 1.0f;
volatile int knob2_reverb_val = 0, knob2_size_val = 50, knob2_decay_val = 75;
volatile int knob3_time_val = 50, knob3_feedback_val = 50, knob3_mix_val = 0;
volatile float delay_time_samples = 0;
volatile float delay_feedback = 0.0f;
volatile float delay_mix = 0.0f;

bool reverse_mode = false;
volatile size_t record_counter = 0;
volatile size_t recorded_samples = 0;
volatile size_t play_position_samples = 0;
volatile bool speaker_muted = false;
bool has_undo_state = false;
unsigned long play_button_press_time = 0;
bool play_button_long_press_actioned = false;
int original_pitch = 0;
bool waveform_ready = false;
volatile bool waveform_display_needs_update = false;
float waveform_scale = 1.0f;
volatile size_t loop_start_sample = 0;
volatile size_t loop_end_sample = 0;
bool loop_edit_mode = false;

struct WaveformPixel { float min; float max; };
const int DISPLAY_W = (SCREEN_WIDTH - 5 * 2);
WaveformPixel displayWaveform[160];

struct Star { float x, y, z; float speed; };
#define MAX_STARS 100
Star stars[MAX_STARS];

//====================================================================
// --- CONSTANTES DE DISEÑO Y PALETA DE COLORES ---
//====================================================================
#define COLOR(r, g, b) (((r & 0xF8) << 8) | ((g & 0xFC) << 3) | (b >> 3))
const uint16_t C_BG = COLOR(10, 15, 25);
const uint16_t C_GRID = COLOR(30, 40, 60);
const uint16_t C_TEXT_LIGHT = COLOR(200, 220, 255);
const uint16_t C_TEXT_DARK = COLOR(100, 110, 130);
const uint16_t C_ACCENT_CYAN = COLOR(0, 255, 255);
const uint16_t C_ACCENT_MAGENTA = COLOR(255, 0, 255);
const uint16_t C_ACCENT_ORANGE = COLOR(0, 165, 255);
const uint16_t C_STATE_REC = COLOR(0, 0, 255);

const int STATUS_Y = 10;
const int WAVEFORM_X = 5, WAVEFORM_Y = 25, WAVEFORM_W = 300, WAVEFORM_H = 45;
const int KNOBS_Y = 85;

// Forward Declaration needed
void updateRgbLed(LooperState state);

//====================================================================
// --- LÓGICA DE ENCODERS POR INTERRUPCIÓN (ISR) ---
//====================================================================
volatile unsigned long last_isr_time_1 = 0;
volatile unsigned long last_isr_time_2 = 0;
volatile unsigned long last_isr_time_3 = 0;

void encoder1_isr() {
  if (micros() - last_isr_time_1 < 3000) return;
  last_isr_time_1 = micros();
  if (digitalRead(ENC1_DT_PIN) == digitalRead(ENC1_CLK_PIN)) {
    enc1_counter++;
  } else {
    enc1_counter--;
  }
}

void encoder2_isr() {
  if (micros() - last_isr_time_2 < 3000) return;
  last_isr_time_2 = micros();
  if (digitalRead(ENC2_DT_PIN) == digitalRead(ENC2_CLK_PIN)) {
    enc2_counter++;
  } else {
    enc2_counter--;
  }
}

void encoder3_isr() {
  if (micros() - last_isr_time_3 < 3000) return;
  last_isr_time_3 = micros();
  if (digitalRead(ENC3_DT_PIN) == digitalRead(ENC3_CLK_PIN)) {
    enc3_counter++;
  } else {
    enc3_counter--;
  }
}

void encoder4_isr() {
  if (micros() - last_isr_time_4 < 3000) return;
  last_isr_time_4 = micros();
  if (digitalRead(ENC4_DT_PIN) == digitalRead(ENC4_CLK_PIN)) {
    enc4_counter++;
  } else {
    enc4_counter--;
  }
}


void generarOndaVisual_AbletonStyle(WaveformPixel* displayBuf, int displayLen, float* audioBuf, size_t audioLen) {
  if (audioLen == 0 || displayLen <= 0) return;
  int samples_per_pixel = (int)(audioLen / displayLen);
  if (samples_per_pixel < 4) samples_per_pixel = 4;

  for (int i = 0; i < displayLen; i++) {
    size_t chunk_start = (size_t)i * samples_per_pixel;
    size_t chunk_end = chunk_start + samples_per_pixel;
    if (chunk_start >= audioLen) {
      displayBuf[i].min = 0.0f;
      displayBuf[i].max = 0.0f;
      continue;
    }
    if (chunk_end > audioLen) chunk_end = audioLen;
    float sum_sq = 0.0f;
    float min_val = 1.0f;
    float max_val = -1.0f;
    for (size_t j = chunk_start; j < chunk_end; j++) {
      float s = audioBuf[j];
      sum_sq += s * s;
      if (s < min_val) min_val = s;
      if (s > max_val) max_val = s;
    }
    float rms = sqrtf(sum_sq / (float)(chunk_end - chunk_start));
    const float blend = 0.65f;
    float vis_max = (max_val * blend) + (rms * (1.0f - blend));
    float vis_min = (min_val * blend) - (rms * (1.0f - blend));
    displayBuf[i].min = vis_min;
    displayBuf[i].max = vis_max;
  }
}

void drawBackground() {
  uint8_t r_start = 5, g_start = 10, b_start = 25;
  for (int y = 0; y < SCREEN_HEIGHT; y++) {
    uint8_t b = b_start - (y * b_start / SCREEN_HEIGHT);
    uint8_t g = g_start - (y * g_start / SCREEN_HEIGHT);
    uint8_t r = r_start - (y * r_start / SCREEN_HEIGHT);
    canvas->drawFastHLine(0, y, SCREEN_WIDTH, COLOR(r, g, b));
  }
  float center_x = SCREEN_WIDTH / 2.0;
  float center_y = SCREEN_HEIGHT / 2.0;
  for (int i = 0; i < MAX_STARS; i++) {
    stars[i].z -= stars[i].speed * 0.2;
    if (stars[i].z <= 0.5) {
      stars[i].x = random(-SCREEN_WIDTH / 2, SCREEN_WIDTH / 2);
      stars[i].y = random(-SCREEN_HEIGHT / 2, SCREEN_HEIGHT / 2);
      stars[i].z = random(8, 15);
      stars[i].speed = (15.0 - stars[i].z) * 0.3 + 0.5;
    }
    float perspective_scale = 1.0 / stars[i].z;
    int display_x = (int)(center_x + stars[i].x * perspective_scale * 5);
    int display_y = (int)(center_y + stars[i].y * perspective_scale * 5);
    uint16_t star_color = COLOR(200, 200, 200);
    int star_size = 1;
    if (stars[i].z < 3) {
      star_color = COLOR(255, 255, 255);
      star_size = 2;
    } else if (stars[i].z < 6) {
      star_color = COLOR(220, 220, 215);
    }
    if (display_x >= 0 && display_x < SCREEN_WIDTH && display_y >= 0 && display_y < SCREEN_HEIGHT) {
      if (star_size > 1) {
        canvas->fillRect(display_x, display_y, star_size, star_size, star_color);
      } else {
        canvas->drawPixel(display_x, display_y, star_color);
      }
    }
  }
}

void drawSplashScreen(float progress) {
  drawBackground();
  const char* title = "SAMPLER";
  int16_t x1, y1;
  uint16_t w, h;
  canvas->setFont(NULL);
  canvas->setTextSize(3);
  canvas->getTextBounds(title, 0, 0, &x1, &y1, &w, &h);
  int16_t cursor_x = (SCREEN_WIDTH - w) / 2;
  int bar_height = 8;
  int spacing = 12;
  int total_content_height = h + spacing + bar_height;
  int16_t cursor_y = (SCREEN_HEIGHT - total_content_height) / 2;
  canvas->setCursor(cursor_x, cursor_y);
  canvas->setTextColor(C_ACCENT_CYAN);
  canvas->print(title);
  int bar_width = 100;
  int bar_x = (SCREEN_WIDTH - bar_width) / 2;
  int bar_y = cursor_y + h + spacing;
  canvas->drawRect(bar_x, bar_y, bar_width, bar_height, C_TEXT_LIGHT);
  int progress_width = (int)(progress * (float)(bar_width - 4));
  if (progress_width > 0) {
    canvas->fillRect(bar_x + 2, bar_y + 2, progress_width, bar_height - 4, C_ACCENT_CYAN);
  }
}
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
void loop() {

  static unsigned long last_jack_check = 0;
  if (millis() - last_jack_check > 200) {
    last_jack_check = millis();

    if (digitalRead(JACK_DETECT_PIN) != LOW) {
      speaker_muted = true;
    } else {
      speaker_muted = false;
    }
  }
  noInterrupts();
  int e1 = enc1_counter; int e2 = enc2_counter; int e3 = enc3_counter; int e4 = enc4_counter;
  interrupts();
  int e1_delta = e1 - last_e1; last_e1 = e1;
  int e4_delta = e4 - last_e4; last_e4 = e4;

  bool enc4_sw = digitalRead(ENC4_SW_PIN);
  if (last_enc4_sw_state == HIGH && enc4_sw == LOW) {
    if (enc4_mode == ENC4_MODE_GAIN) enc4_mode = ENC4_MODE_START_POINT;
    else if (enc4_mode == ENC4_MODE_START_POINT) enc4_mode = ENC4_MODE_END_POINT;
    else if (enc4_mode == ENC4_MODE_END_POINT) enc4_mode = ENC4_MODE_MOVE;
    else enc4_mode = ENC4_MODE_GAIN;
    noInterrupts(); enc4_counter = 0; last_e4 = 0; interrupts();
  }
  last_enc4_sw_state = enc4_sw;

  if (e4_delta != 0 && recorded_samples > 0) {
    int sensitivity = max(1, (int)(recorded_samples / 500));
    long delta = (long)e4_delta * sensitivity;
    switch (enc4_mode) {
      case ENC4_MODE_START_POINT: {
        long new_start = (long)loop_start_sample + delta;
        if (new_start < 0) new_start = 0;
        if (new_start >= loop_end_sample) new_start = (loop_end_sample > 0) ? (loop_end_sample - 1) : 0;
        loop_start_sample = (size_t)new_start; break;
      }
      case ENC4_MODE_END_POINT: {
        long new_end = (long)loop_end_sample + delta;
        if (new_end <= loop_start_sample) new_end = loop_start_sample + 1;
        if (new_end >= recorded_samples) new_end = recorded_samples - 1;
        if (new_end < 0) new_end = 0;
        loop_end_sample = (size_t)new_end; break;
      }
      case ENC4_MODE_MOVE: {
        long new_start = (long)loop_start_sample + delta;
        long new_end = (long)loop_end_sample + delta;
        if (new_start < 0) { new_start = 0; new_end = (loop_end_sample - loop_start_sample); }
        if (new_end >= recorded_samples) { new_end = recorded_samples - 1; new_start = new_end - (loop_end_sample - loop_start_sample); }
        if (new_start < 0) new_start = 0;
        if (new_start >= new_end) { new_start = new_end - 1; if (new_start < 0) new_start = 0; }
        loop_start_sample = (size_t)new_start; loop_end_sample = (size_t)new_end; break;
      }
      case ENC4_MODE_GAIN: {
        g_gain += (float)e4_delta * 0.01f; g_gain = constrain(g_gain, 0.0f, 2.0f); break;
      }
    }
    looper.SetLoopRegion(loop_start_sample, loop_end_sample);
  }

  // ENC1
  switch (enc1_mode) {
    case PITCH: {
        int pitch_semitones = e1 / PITCH_SENSITIVITY;
        pitch_semitones = constrain(pitch_semitones, -6, 6);
        g_current_pitch_ratio = powf(2.0f, (float)pitch_semitones / 12.0f);
        looper.SetPlaybackSpeed(g_current_pitch_ratio);
      } break;
    case HIGHPASS: {
        e1 = constrain(e1, 0, 100); noInterrupts(); enc1_counter = e1; interrupts();
        g_highpass_filter->SetFreq(20.0f * powf(500.0f, (float)e1 / 100.0f));
      } break;
    case LOWPASS: {
        e1 = constrain(e1, 0, 100); noInterrupts(); enc1_counter = e1; interrupts();
        g_lowpass_filter->SetFreq(200.0f * powf(100.0f, (float)e1 / 100.0f));
      } break;
  }

  // ENC2, ENC3
  e2 = constrain(e2, 0, 100); e3 = constrain(e3, 0, 100);
  noInterrupts(); enc2_counter = e2; enc3_counter = e3; interrupts();

  bool enc2_sw = digitalRead(ENC2_SW_PIN);
  if (last_enc2_sw_state == HIGH && enc2_sw == LOW) {
    if (knob2_mode == REVERB) { knob2_mode = SIZE; enc2_counter = knob2_size_val; }
    else if (knob2_mode == SIZE) { knob2_mode = DECAY; enc2_counter = knob2_decay_val; }
    else { knob2_mode = REVERB; enc2_counter = knob2_reverb_val; }
  }
  last_enc2_sw_state = enc2_sw;
  reverb_effect->SetFeedback(((float)knob2_decay_val / 100.0f) * 0.70f);
  reverb_effect->SetLpFreq(500.0f + ((float)knob2_size_val / 100.0f * 15000.0f));

  bool fn_button = digitalRead(FN_BUTTON_PIN);
  if (last_fn_button_state == HIGH && fn_button == LOW) loop_edit_mode = !loop_edit_mode;
  last_fn_button_state = fn_button;

  switch (knob2_mode) {
    case REVERB: knob2_reverb_val = e2; break;
    case SIZE: knob2_size_val = e2; break;
    case DECAY: knob2_decay_val = e2; break;
  }
  bool enc3_sw = digitalRead(ENC3_SW_PIN);
  if (last_enc3_sw_state == HIGH && enc3_sw == LOW) {
    if (knob3_mode == TIME) { knob3_mode = DELAY; enc3_counter = knob3_feedback_val; }
    else if (knob3_mode == DELAY) { knob3_mode = MIX; enc3_counter = knob3_mix_val; }
    else { knob3_mode = TIME; enc3_counter = knob3_time_val; }
  }
  last_enc3_sw_state = enc3_sw;
  switch (knob3_mode) {
    case TIME: { knob3_time_val = e3; float delay_ms = (float)knob3_time_val / 100.0f * 100.0f; if (delay_ms < 1.0f) delay_ms = 1.0f; delay_time_samples = DAISY.AudioSampleRate() / 1000.0f * delay_ms; } break;
    case DELAY: delay_feedback = (float)e3 / 100.0f * 0.70f; knob3_feedback_val = e3; break;
    case MIX: delay_mix = (float)e3 / 100.0f; knob3_mix_val = e3; break;
  }

  noInterrupts(); size_t current_recorded_samples = record_counter; interrupts();
  if (current_recorded_samples > 0) {
    float max_abs_val = 1e-6f;
    for (size_t i = 0; i < current_recorded_samples; i++) {
        float a = fabsf(waveform_source_buffer[i]); if (a > max_abs_val) max_abs_val = a;
    }
    if (max_abs_val < 1e-6f) max_abs_val = 1e-6f;
    waveform_scale = ((WAVEFORM_H / 2.0f) / max_abs_val) * 0.7f;
    generarOndaVisual_AbletonStyle(displayWaveform, DISPLAY_W, waveform_source_buffer, current_recorded_samples);
    waveform_ready = true;
  } else waveform_ready = false;
  waveform_display_needs_update = false;

  bool rec_button = digitalRead(REC_BUTTON_PIN);
  bool play_button = digitalRead(PLAY_BUTTON_PIN);
  bool stop_button = digitalRead(STOP_BUTTON_PIN);
  bool reset_button = digitalRead(RESET_BUTTON_PIN);

  if (last_reset_button_state == HIGH && reset_button == LOW) {
    unsigned long currentTime = millis();
    if (currentTime - last_reset_press_time < DOUBLE_PRESS_TIME_MS) reset_press_count++; else reset_press_count = 1;
    last_reset_press_time = currentTime;
    if (reset_press_count == 2) {
      if (recorded_samples > 0) {
        loop_start_sample = 0; loop_end_sample = recorded_samples - 1;
        looper.SetLoopRegion(loop_start_sample, loop_end_sample);
      }
      reset_press_count = 0;
    }
  }
  if (reset_press_count == 1 && (millis() - last_reset_press_time > DOUBLE_PRESS_TIME_MS)) {
    resetSystem(); reset_press_count = 0;
  }
  last_reset_button_state = reset_button;

  if (last_enc1_sw_state == HIGH && digitalRead(ENC1_SW_PIN) == LOW) {
    if (enc1_mode == PITCH) enc1_mode = HIGHPASS; else if (enc1_mode == HIGHPASS) enc1_mode = LOWPASS; else enc1_mode = PITCH;
  }
  last_enc1_sw_state = digitalRead(ENC1_SW_PIN);

  bool rec_button_is_pressed = (rec_button == LOW);
  bool rec_button_was_pressed = (last_rec_button_state == LOW);
  if (rec_button_is_pressed && !rec_button_was_pressed) {
    if (looper_state == STOPPED) {
      memset(buffer, 0, sizeof(float) * kBufferLengthSamples);
      looper.StartRecording(); looper_state = RECORDING;
      recorded_samples = 0; record_counter = 0; has_undo_state = false; waveform_ready = false;
    } else if (looper_state == PLAYING) {
      looper.StartOverdub(); looper_state = OVERDUB;
    }
  }
  if (!rec_button_is_pressed && rec_button_was_pressed) {
    if (looper_state == RECORDING) {
      looper.StopRecording(); recorded_samples = record_counter;
      loop_start_sample = 0; loop_end_sample = recorded_samples > 0 ? recorded_samples - 1 : 0;
      looper.SetLoopRegion(loop_start_sample, loop_end_sample);
      looper_state = PLAYING;
    } else if (looper_state == OVERDUB) {
      looper.StopOverdub(); looper_state = PLAYING;
    }
  }
  last_rec_button_state = rec_button;
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

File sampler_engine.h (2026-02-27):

#pragma once
// SAMPLER CNA - Audio Engine
#include <string.h>

namespace crearttech {

/**
 * @class OverdubLooper
 * @brief Motor principal del looper con grabación, reproducción, overdub y undo/redo.
 */
class OverdubLooper {
public:
  /**
   * @brief Prepara el looper para su uso.
   * @param buf Puntero a un búfer de memoria (ej. en la SDRAM) donde se guardará el audio.
   * @param length La longitud total de ese búfer en número de muestras.
   * @param undo_bufs Array de punteros a buffers de undo (opcional, puede ser nullptr)
   * @param num_undo_levels Número de niveles de undo disponibles (max MAX_UNDO_LEVELS)
   */
  void Init(float *buf, size_t length, float** undo_bufs = nullptr, size_t num_undo_levels = 0) {
    uintptr_t addr = reinterpret_cast<uintptr_t>(buf);
    if (addr % 32 != 0) {
      #ifdef DEBUG
      Serial.println("WARNING: SDRAM buffer not 32-byte aligned.");
      #endif
    }
    
    _buffer = buf;
    _buffer_length = length;
    
    // Configurar buffers de undo si se proporcionan
    if (undo_bufs != nullptr && num_undo_levels > 0) {
      _undo_enabled = true;
      _undo_count = (num_undo_levels <= MAX_UNDO_LEVELS) ? num_undo_levels : MAX_UNDO_LEVELS;
      for (size_t i = 0; i < _undo_count; i++) {
        _undo_buffers[i] = undo_bufs[i];
      }
    } else {
      _undo_enabled = false;
      _undo_count = 0;
    }
    
    memset(_buffer, 0, sizeof(float) * _buffer_length);
    

    _inv_buffer_length = 1.0f / static_cast<float>(_buffer_length);
    _inv_crossfade_samples = 1.0f / static_cast<float>(CROSSFADE_SAMPLES);
    
    _is_empty = true;
    _reverse = false;
    _playback_speed = 1.0f;
  }

  // --- Funciones de Control de Estado ---

  /** @brief Inicia la grabación desde el principio del búfer. */
  void StartRecording() {
    _rec_head = 0;
    _play_head = 0.0f;
    _is_empty = false;
    _is_recording = true;
    _overdubbing = false;
  }

  /** @brief Detiene la grabación actual y aplica crossfade para transiciones suaves. */
  void StopRecording() { 
    _is_recording = false;
    ApplyCrossfade();
  }

  /** @brief Inicia la sobregrabación (mezcla la entrada con lo que ya hay). */
  void StartOverdub()  { 
    SaveUndoState();
    _overdubbing = true; 
  }

  /** @brief Detiene la sobregrabación. */
  void StopOverdub()   { _overdubbing = false; }

  /** @brief Vuelve a colocar el cabezal de reproducción al inicio del loop. */
  void Restart()       { _play_head = 0; }

  // --- Funciones de Manipulación del Loop ---

  /**
   * @brief Define la sección del búfer que se usará para el loop (obsoleto, usar SetLoopRegion).
   * @param loop_start Posición de inicio normalizada (0.0 a 1.0).
   * @param loop_length Longitud del loop normalizada (0.0 a 1.0).
   */
  void SetLoop(const float loop_start, const float loop_length) {
    _loop_start = static_cast<size_t>(loop_start * (_buffer_length - 1));
    _loop_length = static_cast<size_t>(loop_length * _buffer_length);
    if (_loop_length < 1) _loop_length = 1;
  }

  /**
   * @brief Define la región del loop usando posiciones de muestra exactas.
   * @param start_sample Muestra de inicio.
   * @param end_sample Muestra de fin.
   */
  void SetLoopRegion(size_t start_sample, size_t end_sample) {
      _loop_start = start_sample;
      _loop_length = end_sample - start_sample + 1;
      if (_loop_length < 1) _loop_length = 1;
      if (_play_head >= _loop_length) {
          _play_head = 0;
      }
  }

  /** @brief Activa o desactiva la reproducción en reversa. */
  void SetReverse(bool reverse) { _reverse = reverse; }

  /** @brief Ajusta la velocidad de reproducción. 1.0 es normal, >1.0 es más rápido. */
  void SetPlaybackSpeed(float speed) { _playback_speed = speed; }
  
  /**
   * @brief Configura el tempo para quantización basada en BPM.
   * @param bpm Beats por minuto (ej: 120.0)
   * @param sample_rate Sample rate del sistema (ej: 48000)
   */
  void SetTempo(float bpm, float sample_rate) {
    if (bpm <= 0.0f || sample_rate <= 0.0f) return;
    _bpm = bpm;
    _samples_per_beat = static_cast<size_t>((sample_rate * 60.0f) / bpm);
  }
  
  /**
   * @brief Activa o desactiva la quantización rítmica.
   * @param enable true para activar quantización, false para desactivar
   * @param beats Número de beats a los que quantizar (por defecto 4)
   */
  void SetQuantize(bool enable, size_t beats = 4) {
    _quantize = enable;
    _quantize_beats = (beats > 0) ? beats : 4;
  }
  
  /**
   * @brief Quantiza la longitud grabada al número de beats configurado (método simple).
   * @param recorded_length Longitud grabada original en muestras
   * @return Longitud quantizada en muestras
   */
  size_t QuantizeLength(size_t recorded_length) {
    if (!_quantize || _quantize_beats == 0) return recorded_length;
    

    size_t beat_length = recorded_length / _quantize_beats;
    

    return beat_length * _quantize_beats;
  }
  
  /**
   * @brief Quantiza una región del loop completa (inicio y final) basado en BPM.
   * @param start_sample Posición de inicio grabada (sample absoluto desde que empezó el sistema)
   * @param end_sample Posición de fin grabada (sample absoluto)
   * @param out_start Referencia donde se escribirá el inicio quantizado
   * @param out_end Referencia donde se escribirá el fin quantizado
   */
  void QuantizeLoopRegion(size_t start_sample, size_t end_sample, size_t& out_start, size_t& out_end) {
    if (!_quantize || _samples_per_beat == 0) {
      // Sin quantización, devolver valores originales
      out_start = start_sample;
      out_end = end_sample;
      return;
    }
    
    // Ajustar inicio al beat más cercano
    size_t start_beat = (start_sample + _samples_per_beat / 2) / _samples_per_beat;
    out_start = start_beat * _samples_per_beat;
    
    // Calcular longitud en muestras
    size_t recorded_length = (end_sample > start_sample) ? (end_sample - start_sample) : 0;
    
    // Calcular longitud en beats y redondear
    size_t length_in_beats = (recorded_length + _samples_per_beat / 2) / _samples_per_beat;
    
    // Asegurar que tengamos al menos la cantidad de beats requeridos
    if (length_in_beats < _quantize_beats) {
      length_in_beats = _quantize_beats;
    } else {
      // Redondear al múltiplo de _quantize_beats más cercano
      length_in_beats = ((length_in_beats + _quantize_beats / 2) / _quantize_beats) * _quantize_beats;
    }
    
    // Calcular final basado en el inicio quantizado + longitud quantizada
    out_end = out_start + (length_in_beats * _samples_per_beat);
  }

  
  /**
   * @brief Guarda el estado actual del buffer en el historial de undo.
   * Llamar antes de operaciones destructivas como overdub o ediciones.
   */
  void SaveUndoState() {
    if (!_undo_enabled || _undo_count == 0) return;
    

    memcpy(_undo_buffers[_undo_write_index], 
           _buffer + _loop_start, 
           sizeof(float) * _loop_length);
    

    _undo_write_index = (_undo_write_index + 1) % _undo_count;
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

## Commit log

2026-02-23 Initial commit - SAMPLER CNA Final Version
    [Drill_NPTH_Through.DRL, Drill_PTH_Through.DRL, Drill_PTH_Through_Via.DRL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]
2026-02-23 Fix syntax errors in sampler_engine.h (stray @ error)
    [sampler_engine.h]
2026-02-23 Confirmación de actualización final
2026-02-25 Add files via upload
    Schematics de Diseño Electrónico- SAMPLER CREART.TECH - CNA
2026-02-25 Update and rename 3D-SAMPLER-FRONTAL.stl to PLANOS_MECENICOS_CASE.stl
    [PLANOS_MECENICOS_CASE.stl]
2026-02-25 Update and rename 3D-SAMPLER-TAPA.stl to PLANOS_MECANICOS_CASE_TAPA.stl
    [PLANOS_MECANICOS_CASE_TAPA.stl]
2026-02-25 Update and rename PLANOS_MECENICOS_CASE.stl to PLANOS_MECANICOS_CASE.stl
    [PLANOS_MECANICOS_CASE.stl]
2026-02-25 Rename SAMPLER-CNA.pdf to Planos mecanicos.pdf
